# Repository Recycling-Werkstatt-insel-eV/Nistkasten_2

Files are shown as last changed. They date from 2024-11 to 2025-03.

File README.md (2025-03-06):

# Nistkasten Nr. 2
Bei diesem Vogelhaus bestehen sind alle Materialien entweder wiederverwendbar oder wiederaufbereitet und somit auf jeden Fall nachhaltig und umweltfreundlich. Die Vorderseite ist so konstruiert, dass jede Behausung ein Unikat wird. Die einzelnen Platten sind verschiebbar. Das und die Tatsache, dass alle Komponenten verschraubt sind, macht es komplett auseinandernehmbar. Teile können somit leicht ersetzt, ausgetauscht und gereinigt werden. Je nach Vogelart, ob Höhlen- oder Halbhöhlenbrüter kann die Öffnung der Vogelart angepasst werden. Die Kombination aus recyceltem Kunstoff und Holz erzeugt einen echten Hinkucker. 

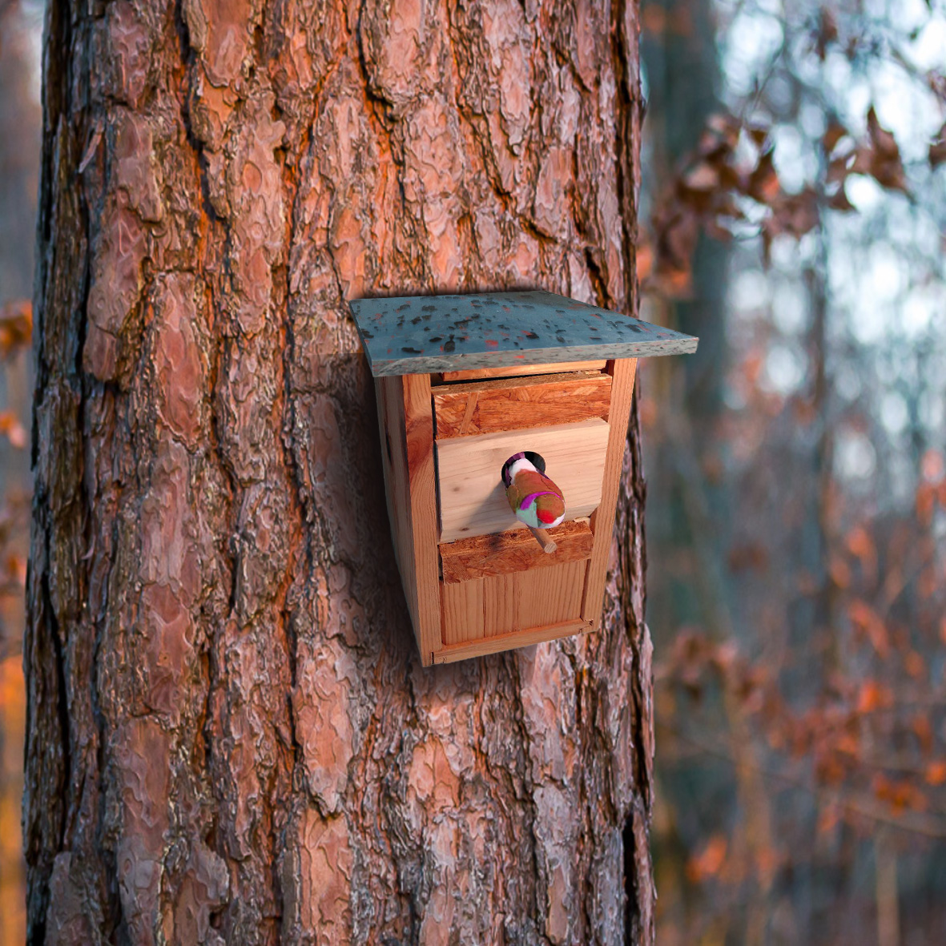
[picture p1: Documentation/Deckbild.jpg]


__Du möchtest dieses Vogelhaus bauen?__ 

Um dieses Vogelhaus nach unserer Methode zu bauen, sieh dir bitte folgende Dokumente an: 

Zum einen empfehlen wir einen Blick in die [Checkliste](./Documentation/Checkliste.md) zu werfen um dir einen Überblick zu machen was es allgemein zu beachten gilt. Anschließend lohnt es sich unseren Vorschlag für die [Fertigung der Einzelteile](./Documentation/Anleitung_Fertigung.md) gewissenhaft zu befolgen, damit die [Anleitung für den Zusammenbau](./Documentation/Anleitung_Aufbau.md) der Einzelteile reibungslos funktioniert. Ergänzend kannst du dir die [Technischen Zeichnungen](./Documentation/Vogelhaus_Ivonne_Technische_Zeichnungen.pdf) dieses Vogelhauses anschauen. Gerade für den Fall, dass du den Entwurf weiterentwickeln möchtest, steht dir jeweils eine [CAD-Datei im STEP Format](./CAD/CAD_Ivonne_Vogelhaus.STEP) und eine
[CAD Datei im STL Format](./3D_printing/CAD_Ivonne_Vogelhaus.STL) zur Verfügung. 

# Allgemeines zum Projekt

Bei diesem Vogelhaus handelt es sich um einen von __4 Entwürfen__ aus einer Reihe innerhalb eines Projekts, in dem wir uns zur Aufgabe gemacht haben, kreative innovative und nachhaltige Ideen für Tierbehausungen zu finden und alte Lösungen zu überdenken. Unseren Fokus haben wir auf Vogelbehausungen gelegt. Und wer sind "wir"? Wir sind Menschen aus der Offenen [Recycling-Werkstatt von Insel e.V.](https://werkstatt.insel-ev.de/) in Hamburg. Besucht uns gerne auf unserer Website oder noch besser persönlich, wir freuen uns auf euch! 

Hier kommt ihr zur [Übersicht](https://github.com/Recycling-Werkstatt-insel-eV/Nistkasten_main_Uebersicht) der folgenden Entwürfe
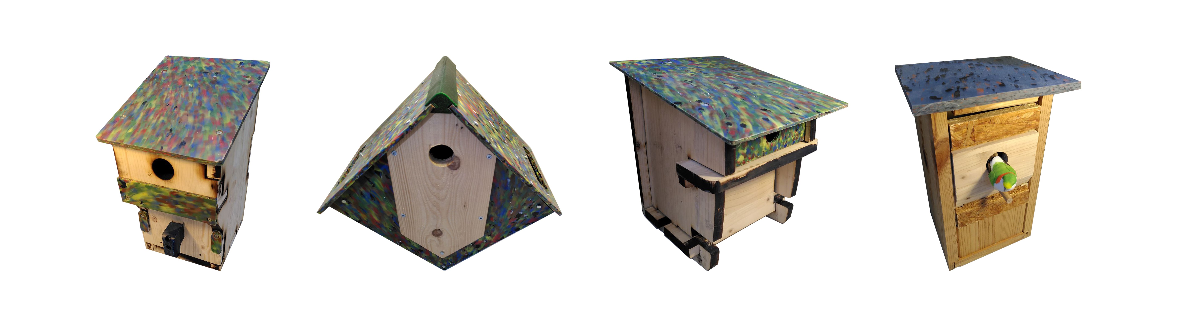
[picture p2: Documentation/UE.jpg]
 
Gefördert von der [Deutschen Stiftung Engagement und Ehrenamt](https://www.deutsche-stiftung-engagement-und-ehrenamt.de/foerderung/) haben wir im Laufe des Jahres 2024 zusammen mit Schüler_innen-Gruppen, Expert_innen vom [NABU](https://www.nabu.de/) und anderen klugen Köpfen getüftelt, wie wir Zeiten, in denen die Umwelt und Natur so schutzbedürftig wie noch nie sind, einen sinnvollen Beitrag leisten können. In Ideen- und Bau- Workshops sind dabei schlussendlich die 4 Konzepte entstanden und umgesetzt worden, die wir euch hier vorstellen wollen. 

__Und was macht unsere Entwürfe besonders?__
Besonders wichtig war uns unter anderem, dass die verwendeten Materialien möglichst nachhaltig sind und eingesetzt werden. Das heißt sie sollen wenig oder gar nicht neu produziert werden müssen. Wir wollen mit Dingen arbeiten, die es schon gibt und diese wieder aufbereiten und neu verwenden. Dafür haben wir in jedem Entwurf recycelten Kunststoff aus unserer Werkstatt verwendet. Dieser besteht aus geschredderten, geschmolzenen zu Platten gepressten Alltagsgegenständen, die sonst in den Müll gewandert wären. Außerdem sind alle Bestandtteile wieder voneinander trennbar. Es wurden keine Klebstoffe und nur wenige Schrauben verwendet. Modulare Systeme ermöglichen zusätzlich das Austauschen und ersetzen einzelner Bestandtteile, sodass die Vogelhäuser leicht repariert werden können und teilweise mehrere Funktionen und Varianten in einem Entwurf beinhalten.  

Aber wie das halt so ist... Kein Entwurf ist perfekt durchdacht. Und genau da kommt ihr ins Spiel. Wir wollen unser Projekt der Community zur Verfügung stellen und euch herzlich einladen die Vogelhäuser __nachzubauen, oder sogar weiterzuentwickeln__. Die Informationen, die  ihr genau dafür benötigt und wie ihr Schritt für Schritt vorgeht, findet ihr in den beiligenden Vogelhaus-Projekten. Von eher unkomplizierten Ideen, die mit einfachen Handwerkzeugen gefertigt werden können, bis hin zu gelaserten oder CNC- gefrästen z.T. herausfordernden Systemen ist für jede_n etwas dabei. Alles kann nichts muss und das gilt auch für die euch zur Verfügung stehenden Mittel. Von uns kommen einige gut gemeinte Ratschläge für die Umsetzung, fühlt euch jedoch gerne frei manches im Sinn eurer Möglichkeiten anders zu machen. Schaut euch gerne um ob und welches Vogelhaus etwas für euch ist, viel Spaß beim bauen und weiterdenken!

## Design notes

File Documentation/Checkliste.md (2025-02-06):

# Checkliste

Unabhängig davon ob ihr eines der Vogelhäuser nachbaut, weiterentwickelt oder einen ganz neuen Entwurf kreiren und aufhängen wollt, gibt es einige wichtige Dinge zu beachten, die für die Umwelt, die Tiere und den Erfolg des Projekts mehr oder weniger wichtig sein können. 
Hier findet ihr eine Übersicht an Checkpunkten an denen wir uns oriententiert haben. 

__Schutz vor Nesträubern__

Viele Tierarten, insbesondere Vögel sind heutzutage stark bedroht. Neben anderen Faktoren sind Nesträuber wie Waschbären, Marder und Hauskatzen dafür verantwortwortlich. Um zu verhindern, dass diese Tiere die Brut der Singvögel bedrohen gibt es bewährte Maßnahmen:

1. Gestalte die Einflugöffnung gerade so groß, dass nur der Nistvogel und vergleichbargroße Arten durchpassen.
2. Baue einen vorgezogenen Zwischenboden in das Vogelhaus, (so wie wir es z.B. bei den Vogelhäusern "Stecksystem" und "Oskar" gemacht haben).
   In dieser Form haben die Räuber Schwierigkeiten bis zur Brut hinunter zu greifen. 
4. Bringe den Vogelkasten idealerweise in einer Höhe von mindestens 2 Metern an, sodass es manchen Räubern schwerer fällt die Brut zu wittern und 
diese zu erreichen.

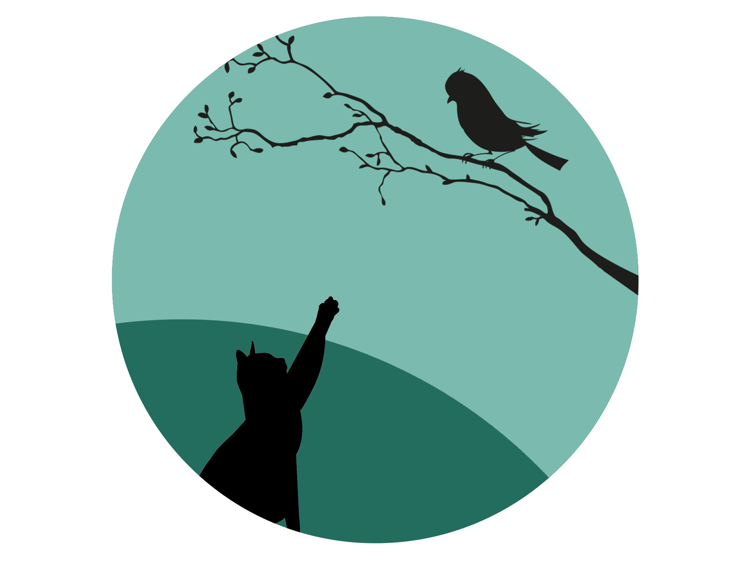
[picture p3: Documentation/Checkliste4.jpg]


__Der passende Ort__

Achte zudem darauf, dass du für dein Vogelhaus einen geeigneten Ort findest, wo sich die Tiere natürlicherweise wohl fühlen. 
Es sollte dort möglichst viel unterschiedliche Vegetation geben, die für viele Lebewesen einen Rückzugsort zum Verstecken und eine wichtige Nahrungsgrundlage bietet. Nur in einem gesunden Ökosystem siedeln sich auch Vögel an um dort zu brüten. Ich denke es sollte klar sein welches der beiden folgenden Beispiele auf dem Bild geeigneter ist.  

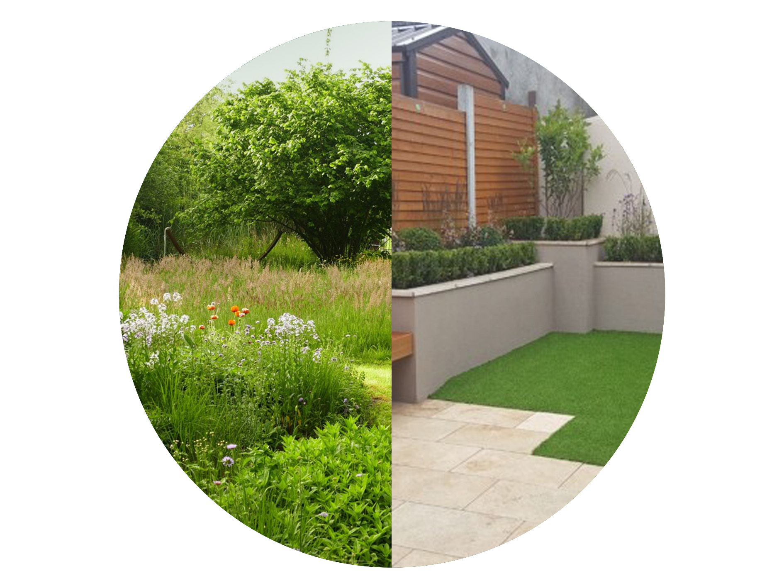
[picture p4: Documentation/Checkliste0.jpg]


__Die richtigen Maße__

Unter dem folgenden Link https://www.nabu-rlp-sued.de/artenschutz/bauanleitungen-f%C3%BCr-nisthilfen/ 
des Nabu Rheinland Pfalz findet ihr viele Infos zu dem Thema, auch die Maße für Vogelhäuser, welche sich etabliert haben um möglichst viele Vogelarten zu erreichen, indem sie gerade groß genug sind und entsprechend Material sparen. Es reicht aber wenn sie euch als ungefährer Anhaltspunkt dienen. 

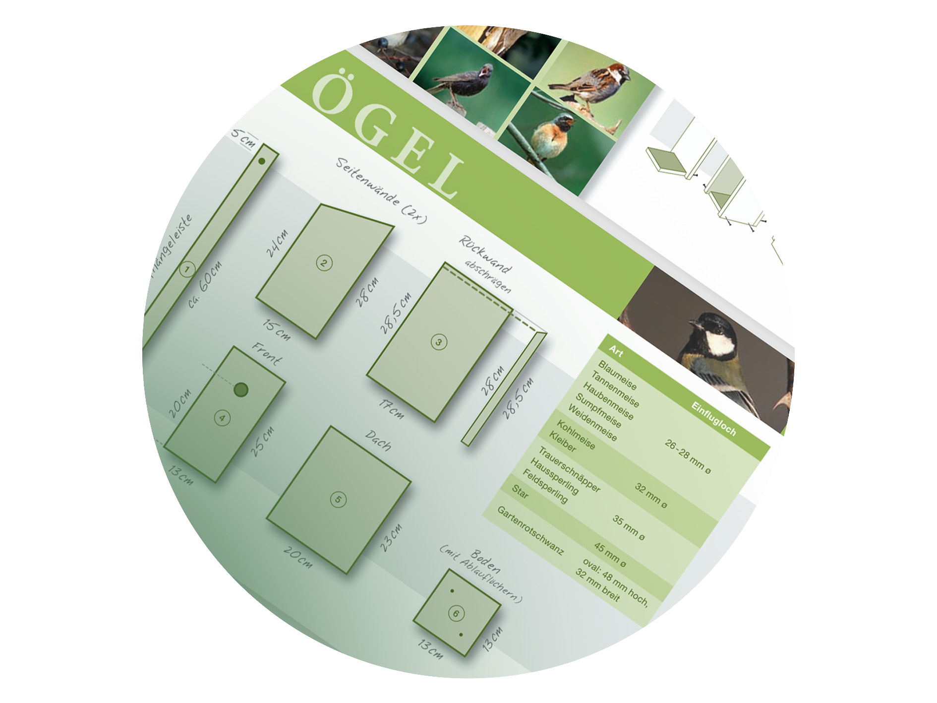
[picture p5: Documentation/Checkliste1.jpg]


__Reinigung des Nistkastens__

Leider müssen Nistkästen ein mal im Jahr nach der Brutsaison gereinigt werden, damit sie sich nicht mit Nistmaterial anfüllen und irgendwann nicht mehr bezogen werden. Gestalte den Kasten also idealerweise so, dass er sich unkompliziert öffnen und reinigen lässt. Die Brutsaison der meisten Singvögel ist im Frühsommer von Mai bis Juli. Ab August lohnt sich der erste Blick ins Innere ob der Mieter mitlerweile ausgezogen ist. 

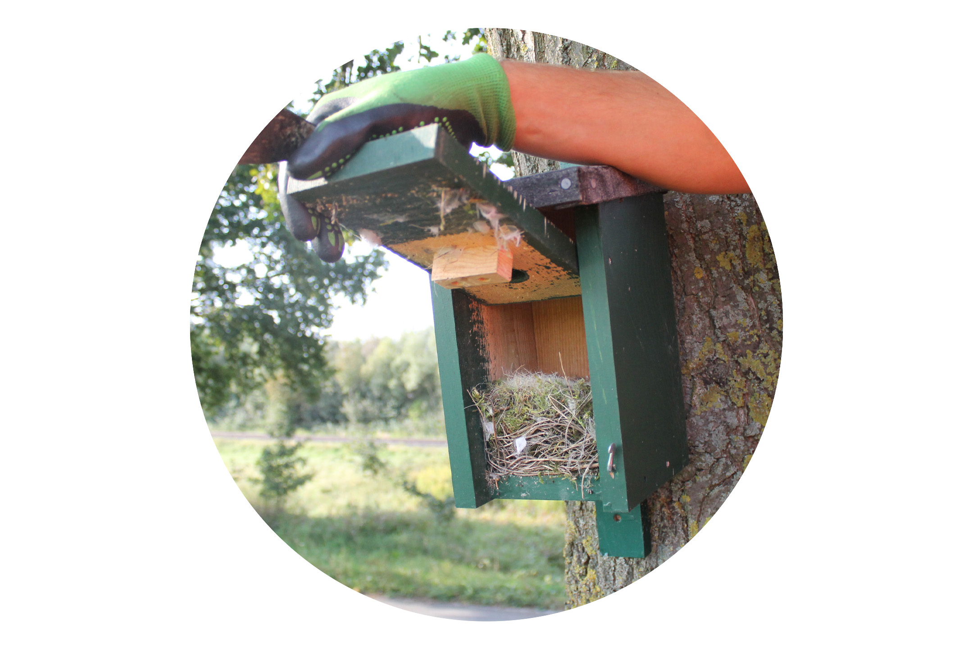
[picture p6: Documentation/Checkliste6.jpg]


__Die ideale Befestigung__

Einfache Eisen- oder Kupfernägel können für einige Baumarten problematisch sein, da sie für diese in einigen Fällen gesundheitsschädlich sind und der Pflanze schaden. Zudem gehen Werkzeuge wie Kettensägen beim Fällen der Bäume kaputt wenn sie in hartes Metall sägen. Um dies zu verhindern ist es ratsam Aluminium-Nägel zu verweden.   

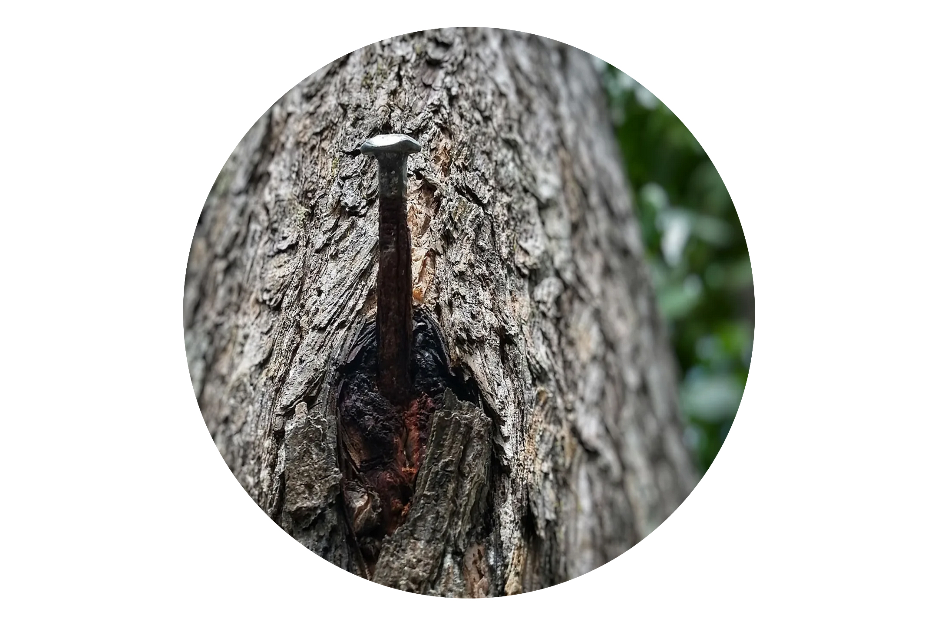
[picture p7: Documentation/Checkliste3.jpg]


__Geeignetes Material__

Die Materialwahl der Tierbehausung ist gleich aus mehreren Gründen besonders wichtig. Beachte dabei bitte folgende Punkte: 

1. Das Material sollte möglichst atmungsaktiv sein, denn wenn das Innere des Hauses mal nass wird und nicht richtig trocknet, kann sich Schimmel bilden, es setzen Fäulnisprozesse ein und Parasiten haben bei den Nestlingen leichteres Spiel. Das schadet der Gesundheit der Brut und verkürzt zudem die Langlebigkeit der Behausung.
2. Achte darauf, dass die verwendeten Materialien nicht vorbehandelt oder beschichtet wurden. In vielen Fällen verstecken sich giftige und umweltschädliche Chemikalien in und auf wiederverwerteten Gegenständen.
3. Denke an die Nachhaltigkeit deiner Materialien. Nachhaltig ist ein Material z.B. dann, wenn es sich mit der Zeit durch die äußeren Einflüsse natürlich zersetzt und komplett wieder in den biologischen Stoffkreislauf zurückgeführt werden kann. Versuche zudem möglichst keine neuen Materialien zu verwenden, sondern bereits existierende Werkstoffe neu aufzubereiten und wiederzuverwenden. Das klappt nicht immer, aber in vielen Fällen. Auch recycelter Kunststoff ist in eingen Fällen deutlich nachhaltiger als manche anderen Alternativen. Bspw. unsere Dächer bestehen aus wasserabweisendem Kunststoff um die Lebensdauer der Behausungen zu verlängern. 

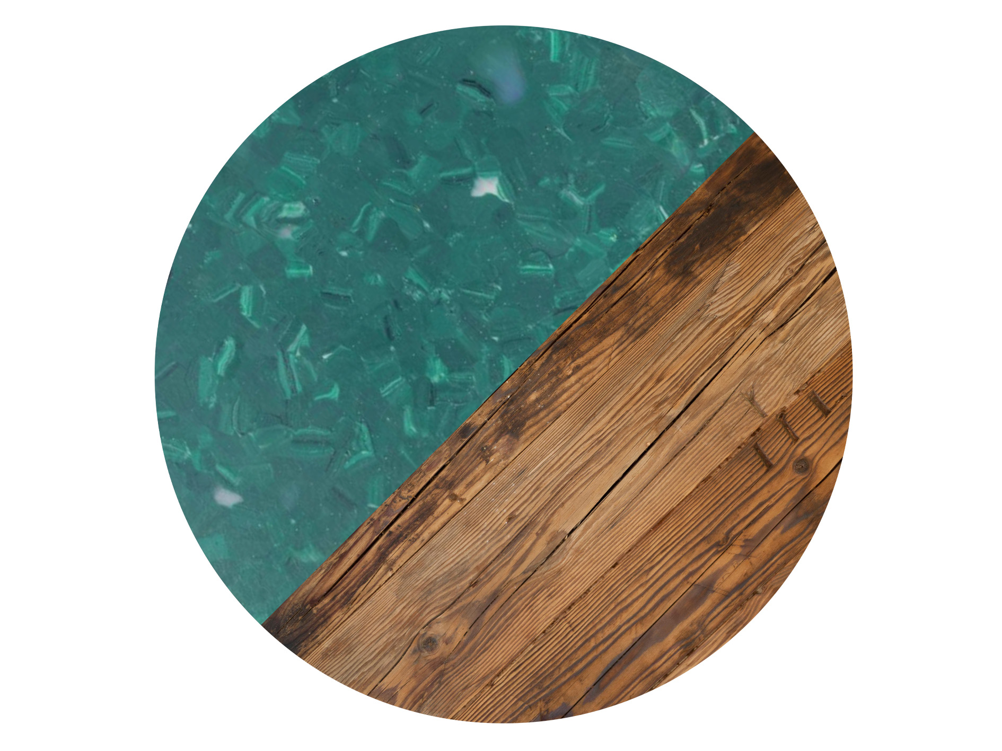
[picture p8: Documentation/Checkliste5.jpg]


Wenn du möglichst viele dieser Punkte beachtest, hast du in deinem Vorhaben schon halb gewonnen.

__Viel Spaß bei der Umsetzung!__

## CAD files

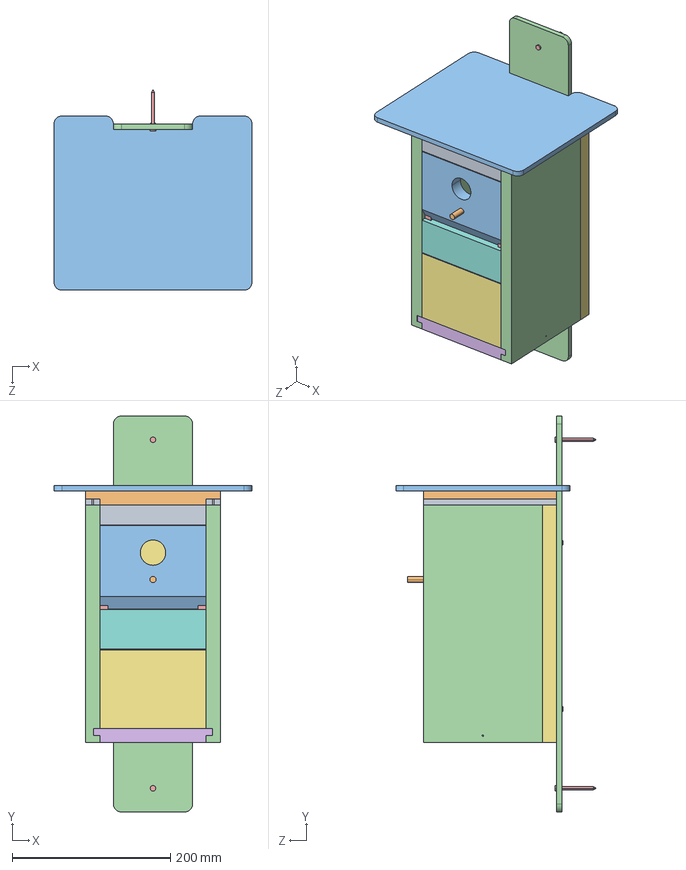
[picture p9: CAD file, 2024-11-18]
CAD/CAD_Ivonne_Vogelhaus.STEP
250.0 x 500.0 x 253.0 mm

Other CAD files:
3D_printing/CAD_Ivonne_Vogelhaus.STL

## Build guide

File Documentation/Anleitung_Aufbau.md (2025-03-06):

# Aufbauanleitung

Hier findet ihr die Bauanleitung von Vogelhaus Nr. 2. Achtet darauf, dass ihr alle entsprechenden Einzelteile im Voraus gefertigt habt, bevor ihr versucht, die Teile zusammenzusetzen. Die Reihenfolge nach dem folgenden Prinzip ist sehr wichtig, damit der Zusammenbau einfach und fehlerfrei abläuft. Bei diesem Beispiel werden 2 Baugruppen hergestellt, die am Ende zusammengesetzt werden. 

__Benötigte Werkzeuge und Hilfsstoffe für den Zusammenbau__

1. Schraubendreher oder Akkuschrauber
3. Schraubzwingen oder mindestens eine helfende Person
4. Schrauben: Für den Bau der Behausung M3 zwischen 12 und 40 mm (12 Stk.)
   und für die Montage Nägel oder Schrauben M3-M5 mit einer Mindestlänge von 80 mm (2 Stk.)
5. Schleifpapier (Körnung 80-200) oder Holzpfeilen für Korrekturen oder abschließende Schönheitsarbeiten.

__Baugruppe 1__ In Baugruppe 1 fertigst du den Hauptkörper des Vogelhauses. 
__Schritt 1__ Zu Beginn werden die hölzernen Seitenwände mit der Bodenplatte verbunden. Hierzu benötigst du 3 Schraueben der Größe M3/M4 mit einer Mindestlänge von 25 mm, also mindestens 7 mm länger als die Platte dick ist (18mm).
__Tipp:__ Benutze einen Schraubstock, Schraubzwingen oder lasse dir beim Zsammenbau helfen, damit die Kanten der Bauteile bündig und rechtwinklig zueinander stehen, wenn du die Schrauben eindrehst. 
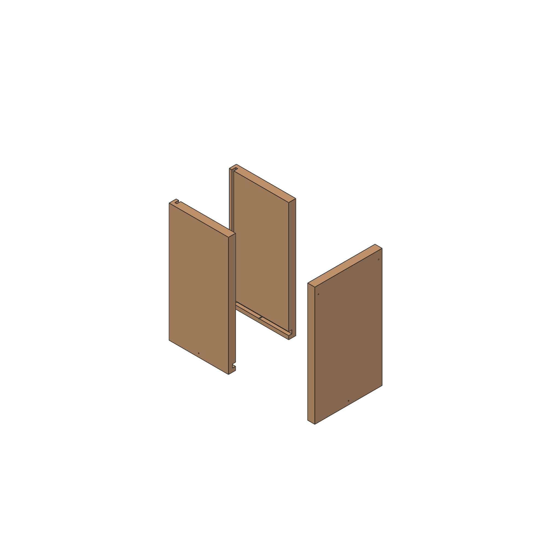
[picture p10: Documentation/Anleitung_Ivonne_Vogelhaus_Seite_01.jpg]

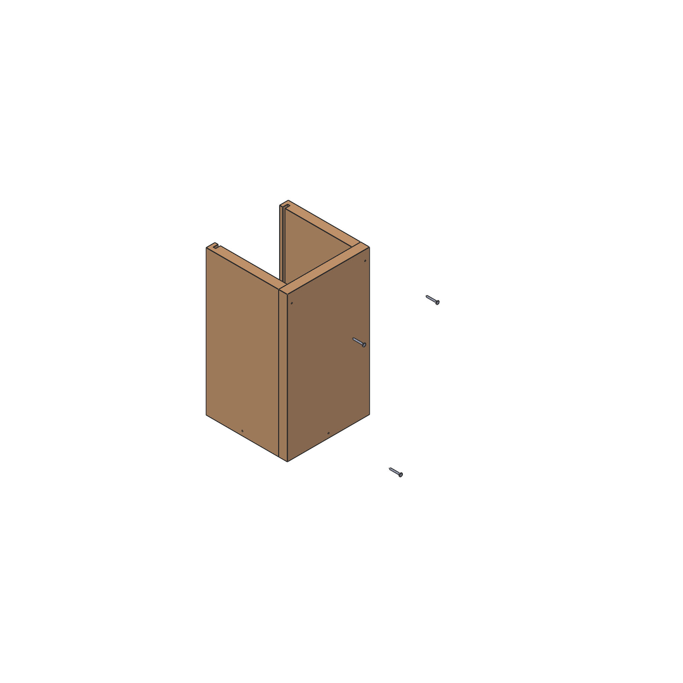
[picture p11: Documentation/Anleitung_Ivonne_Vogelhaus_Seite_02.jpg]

__Schritt 2__ Die Bodenplatte lässt sich nun von vorne in die Baugruppe einschieben. Benutze hierfür gegebenenfalls zusätzlich Schrauben, (M3/M4, Mindestlänge 25 mm) um die Bodenplatte zu fixieren, wie im folgenden dargestellt:
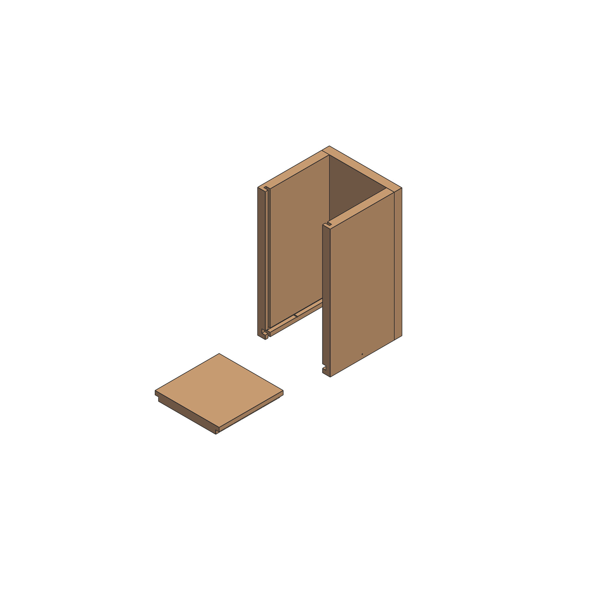
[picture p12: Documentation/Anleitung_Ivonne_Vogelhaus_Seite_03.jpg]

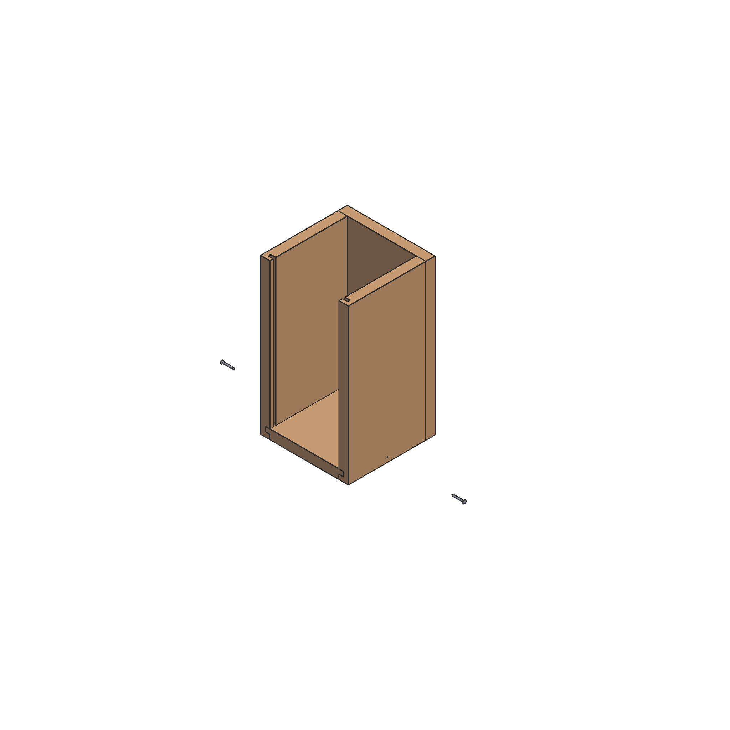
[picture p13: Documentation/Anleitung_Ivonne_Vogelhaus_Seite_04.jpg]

__Schritt 3__ Anschließend werden die länglichen Kunststoffstreifen (282/20/5 mm) von oben in die Nuten der Seitenwände geschoben. Achte darauf, dass diese richtig einrasten und nicht überstehen. 
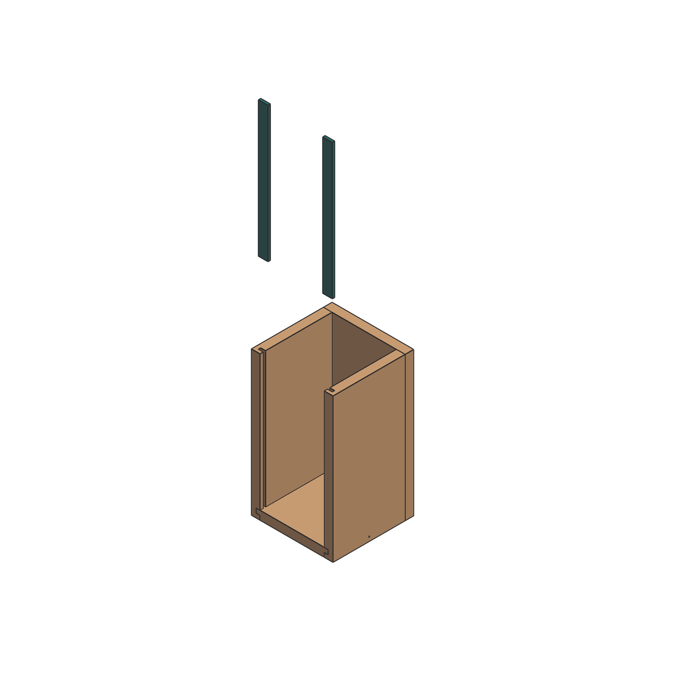
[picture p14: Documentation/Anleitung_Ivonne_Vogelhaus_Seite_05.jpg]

__Schritt 4__ Jetzt kannst du 2 der dünnen Kunstoffstreifen (168/8/8 mm) mit jeweils 2 Schrauben der Größe M3, Länge zwischen 12 und 25 mm befestigen. 
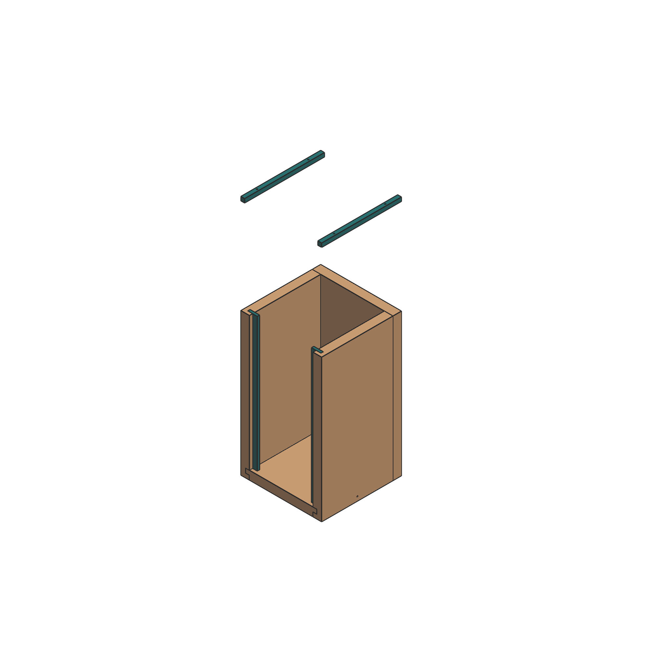
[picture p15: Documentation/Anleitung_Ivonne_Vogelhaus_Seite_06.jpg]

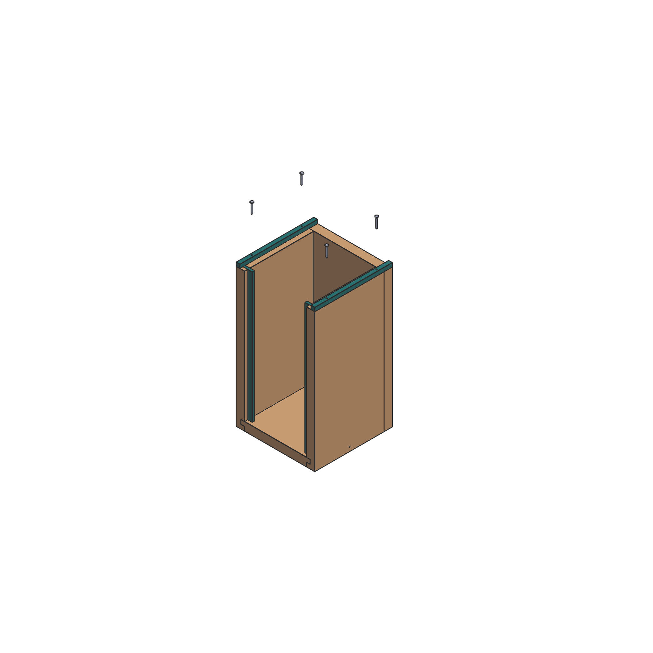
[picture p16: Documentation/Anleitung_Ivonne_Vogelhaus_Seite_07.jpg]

__Schritt 5__ Nun schiebe die Teilstücke der Frontwand in die entstandene Halterung. Achte auch hier darauf, dass kein Teil übersteht, aber auch keine größeren Lücken entstehen.
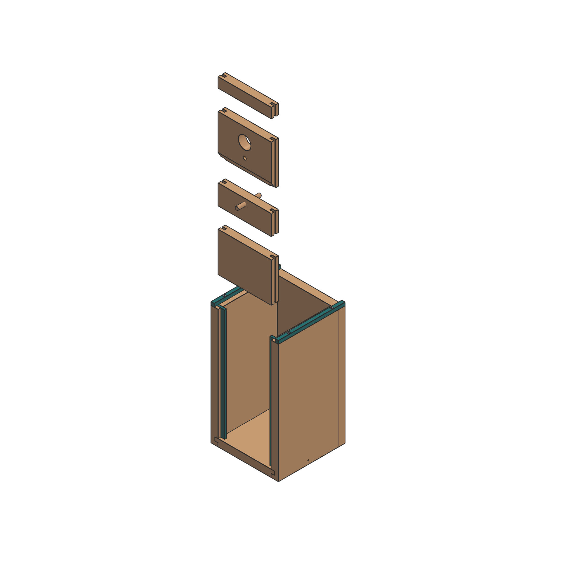
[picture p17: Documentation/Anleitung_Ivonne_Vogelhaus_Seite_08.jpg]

__Baugruppe 2__ In Baugruppe 2 fertigst du das Dach des Hauses. 
__Schritt 6__ Lege die innere Dachplatte aus Holz auf die äußere Dachplatte aus Kunststoff. Auf die eingefrästen Ränder der Holzplatte lege anschließend die verbleibenden 2 Kunststoffstreifen (168/8/8). Hierfür nutze ebenfalls jeweils 2 Schrauben der Größe M3, Länge zwischen 12 und 25 mm
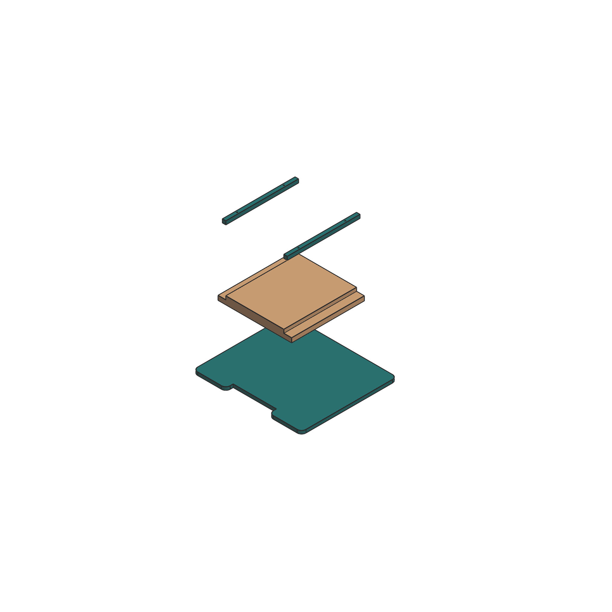
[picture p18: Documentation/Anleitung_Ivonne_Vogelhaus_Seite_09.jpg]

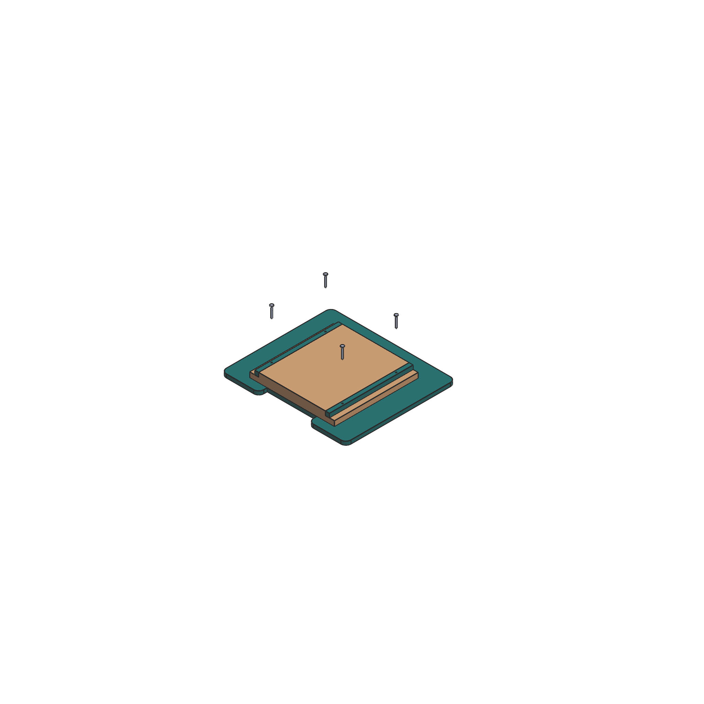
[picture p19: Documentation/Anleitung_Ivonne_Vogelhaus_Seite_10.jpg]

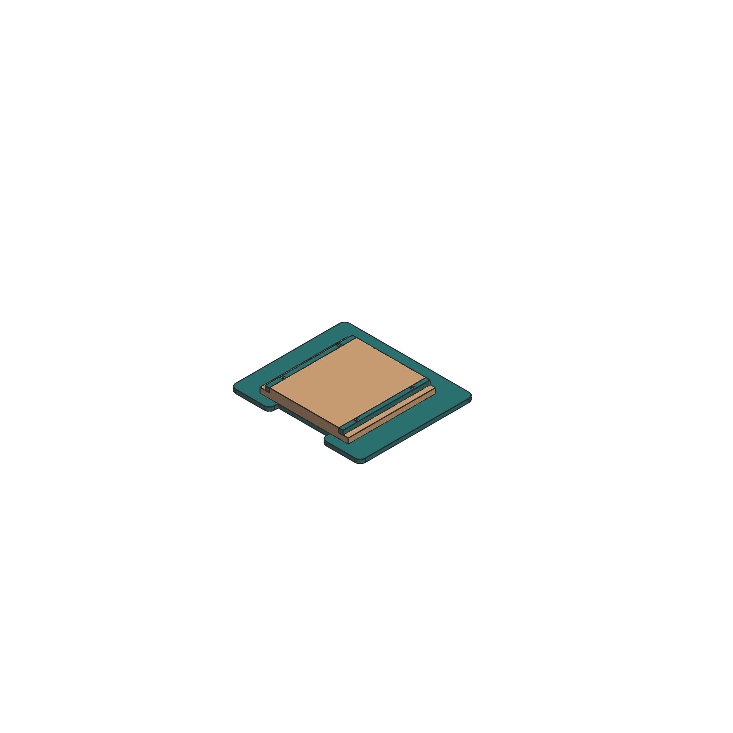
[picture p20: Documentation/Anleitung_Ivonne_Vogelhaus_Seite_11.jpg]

__Zusamnenfügen der Baugruppen 1 und 2__ 

__Schritt 7__ Du kannst nun folgendermaßen das Dach auf den Hauptkörper setzen. Achte darauf, dass die eingefräste Kante des Daches und die Rückwand eine vertikale Linie bilden, damit sich das Kunststoffbrett zur Montage abstandslos befestigen lässt. 
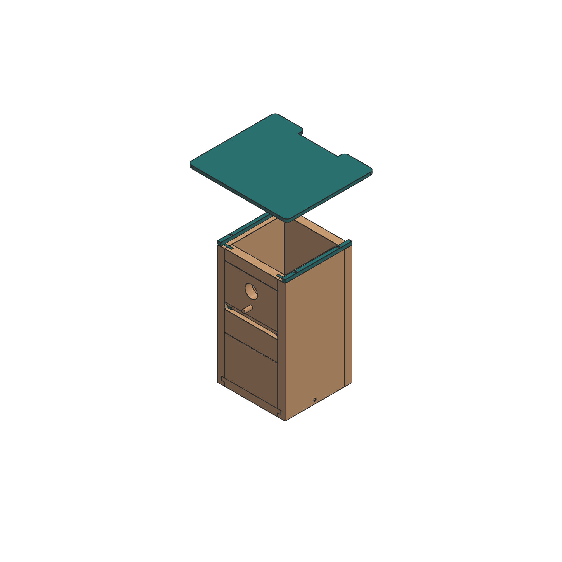
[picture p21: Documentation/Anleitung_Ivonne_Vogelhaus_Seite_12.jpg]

__Schritt 8__ Schraube nun mit 2 M3 Schrauben des Länge 25-28 mm das hintere Brett aus Kunststoff fest. Achte daruaf, dass die Nägel nicht kürzer oder länger als angegeben sind, damit die Konstruktion fest genug hält, die Nägel aber nicht ins Innere der Behausung durchragen. 
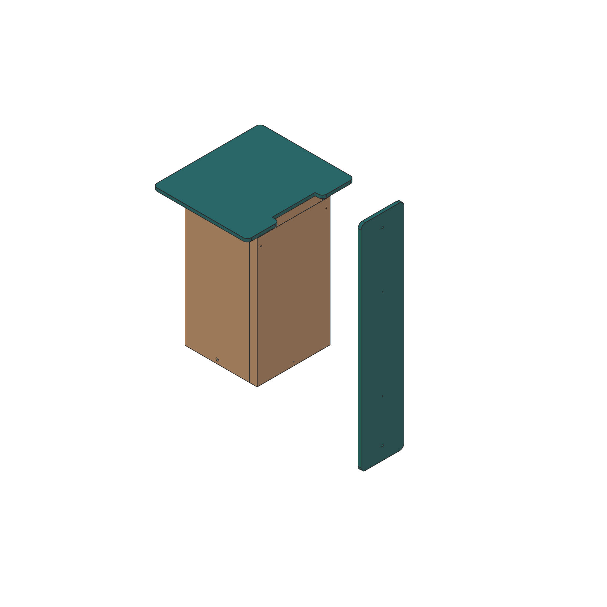
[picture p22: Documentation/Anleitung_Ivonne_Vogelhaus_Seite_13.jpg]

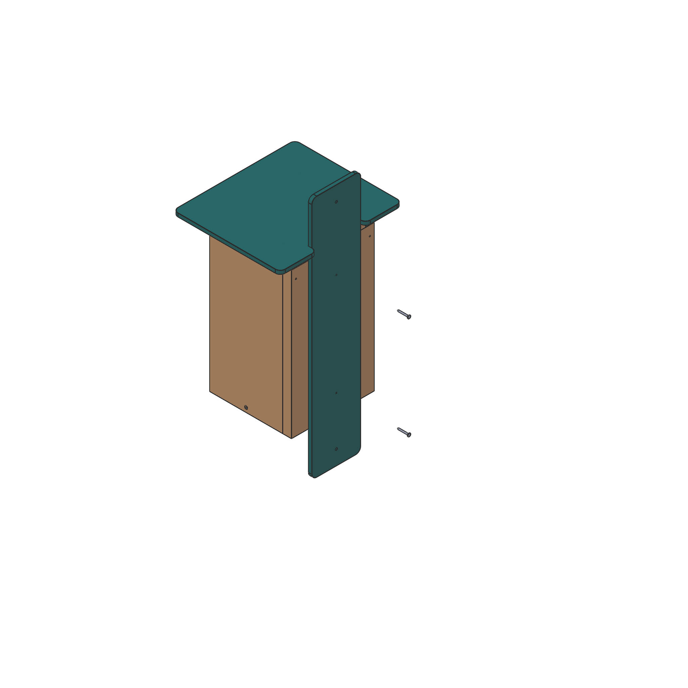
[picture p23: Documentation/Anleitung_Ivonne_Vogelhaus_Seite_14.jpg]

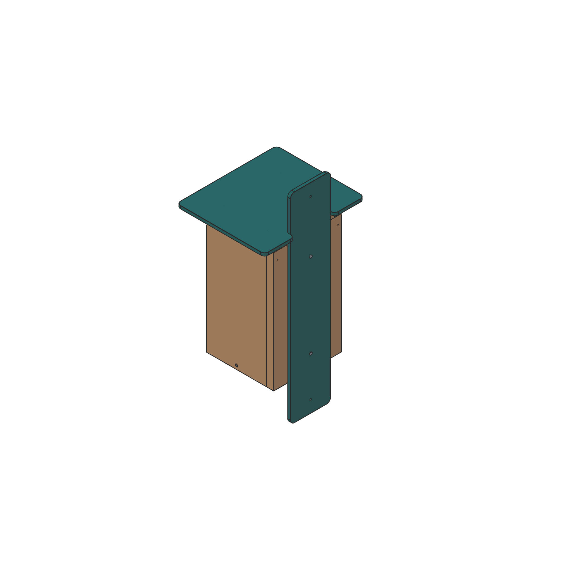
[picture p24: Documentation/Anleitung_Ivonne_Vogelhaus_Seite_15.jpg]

Dein Vogelhaus ist nun __fertig__ aufgebaut.

__Montage__ Jetzt geht es nur noch um die richtige Befestigung beim Aufhängen an einem geeigneten Baum oder bspw. einer Hauswand. Benutze - solltest du dich für einen Baum entscheiden-  wenn möglich Aluminiumnägel mit einer Länge von mindestens 80 mm. Nägel aus Eisen sind aber auch in Ordnung. 
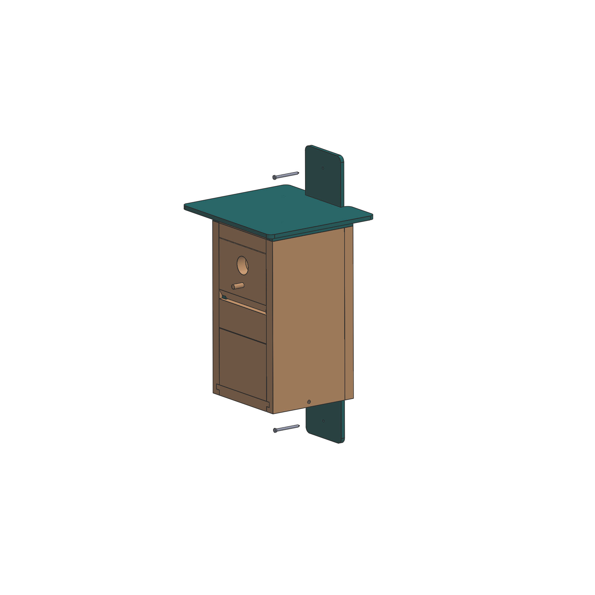
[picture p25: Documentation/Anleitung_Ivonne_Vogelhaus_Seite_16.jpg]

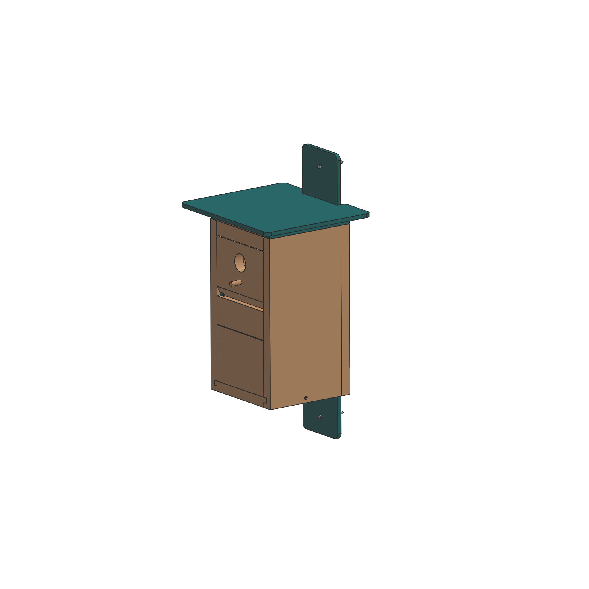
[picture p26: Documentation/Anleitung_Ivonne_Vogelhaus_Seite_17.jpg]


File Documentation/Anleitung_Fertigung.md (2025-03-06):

# Anleitung zur Fertigung der einzelnen Bauteile

Hier und im folgenden ist beschrieben wie beim Bau von Vogelhaus Nr. 2 idealerweise vorgegangen werden kann. 
Es handelt sich um begründete Vorschläge und Tipps, es gibt auch andere Möglichkeiten.

a. __Fräsen der Teile mit CNC__ Hierfür ist bereits Datei als Vorlage angelegt (siehe Repository im Ordner CAD). Im Ordner Dokumentation findest du die technischen Zeichnungen zu allen Bauteilen, solltest du diese erstellen wollen.
   
b.  __Händische Bearbeitung__ mit herkömmlichen Subtraktionswerkzeugen. Dieser Ansatz ist vermutlich am sinnvollsten. Folgende Werkzeuge benötigst du idealerweise:

   - Eine Sägevorrichtung die sowohl gerade als auch schräge Schnitte vollziehen kann. (Bsp. __Tischkreissäge oder Handkreissäge mit Leitwerk__)
     Die Komponenten sind teilweise relativ klein und unhandlich,
     sieh also bitte davon ab diese mit Handwerkzeugen zu bearbeiten um das Verletzungsrisiko zu minimieren.
     Sollte dies unumgänglich sein, spanne die kleinen Teile in einen __Schraubstock oder mit Schraubzwingen__ fest. 
   - Eine Fräse (z.B. __Oberfräse oder Nutfräse__) zum einen, um die Kanten der Bauteile abzurunden und Konturen nachzuarbeiten, aber hauptsächlich, um die Nuten einzufräsen.
   - __Akkuschrauber oder Standbohrmaschine__ um die vorgesehenen Löcher für die Schrauben vorzubohren.
   - __Bohrer in der größe 2mm und 3 mm__
   - Ggf. eine __Feile u.o. Schleifpapier der Körnung 80- 200__ falls Nachbearbeitungen nötig werden sollten.
   - Ein __Hammer und Nägel__ zur Befestigung der Behausung an einem Baum.  

c. __Vorheriges Lasern__ der Teile. Weniger sinnvoll, aber möglich ist es die Komponenten zu lasern, 
da diese nicht nur vertikale Außenkonturen und Löcher haben, 
sondern auch Fasen und Nuten, die schräg oder nur teilweise durchgehend geschnitten werden müssen. 
Nachdem die Konturen geschnitten wurden müssten einzelne weitere Schritte mit anderen Mitteln erfolgen.

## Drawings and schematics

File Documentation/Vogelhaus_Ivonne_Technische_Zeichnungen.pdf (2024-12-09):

E | E
F | F

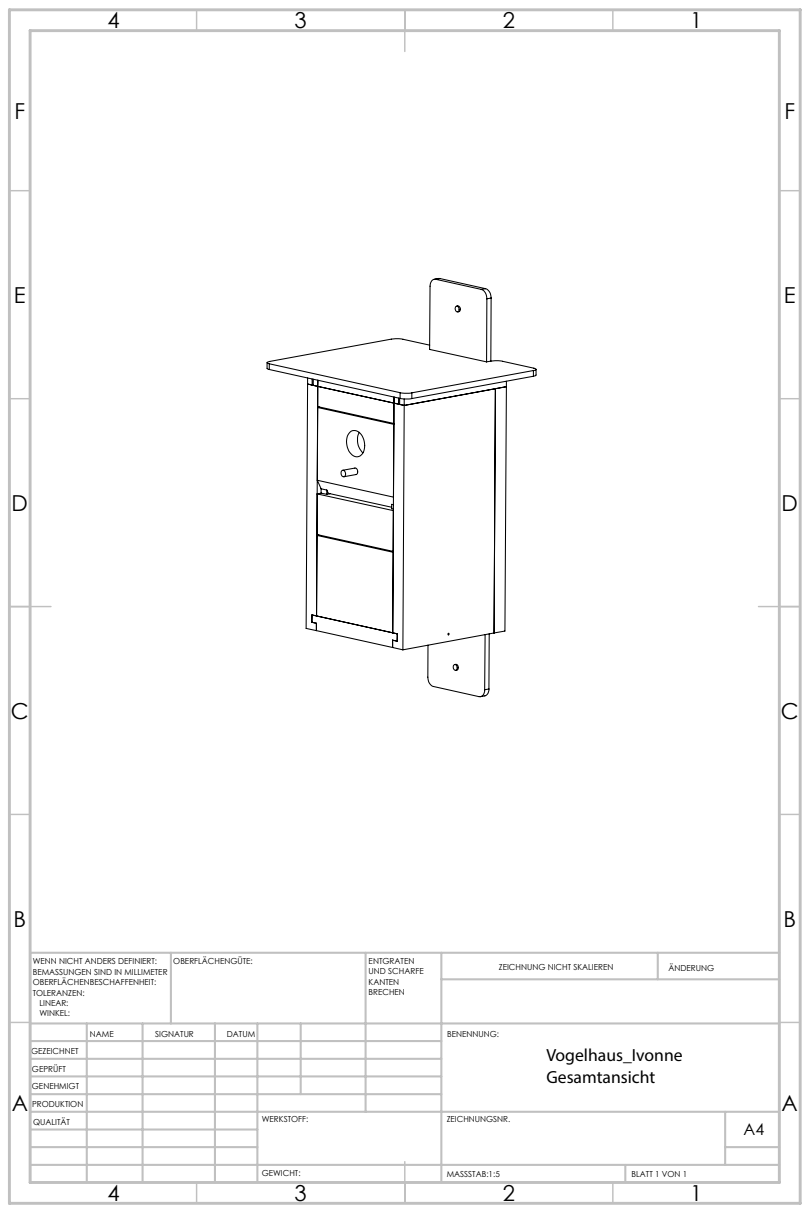
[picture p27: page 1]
GEWICHT:; MASSSTAB:1:5; BLATT 1 VON 1; ZEICHNUNG NICHT SKALIEREN; ÄNDERUNG; ENTGRATEN UND SCHARFE KANTEN BRECHEN; WENN NICHT ANDERS DEFINIERT:; OBERFLÄCHENGÜTE:

BEMASSUNGEN SIND IN MILLIMETER
OBERFLÄCHENBESCHAFFENHEIT:
TOLERANZEN:
LINEAR:
WINKEL:

NAME | SIGNATUR | DATUM | BENENNUNG: Vogelhaus_Ivonne Gesamtansicht
GEZEICHNET
GEPRÜFT
GENEHMIGT
PRODUKTION
QUALITÄT | WERKSTOFF: | ZEICHNUNGSNR. | A4

A

250,00

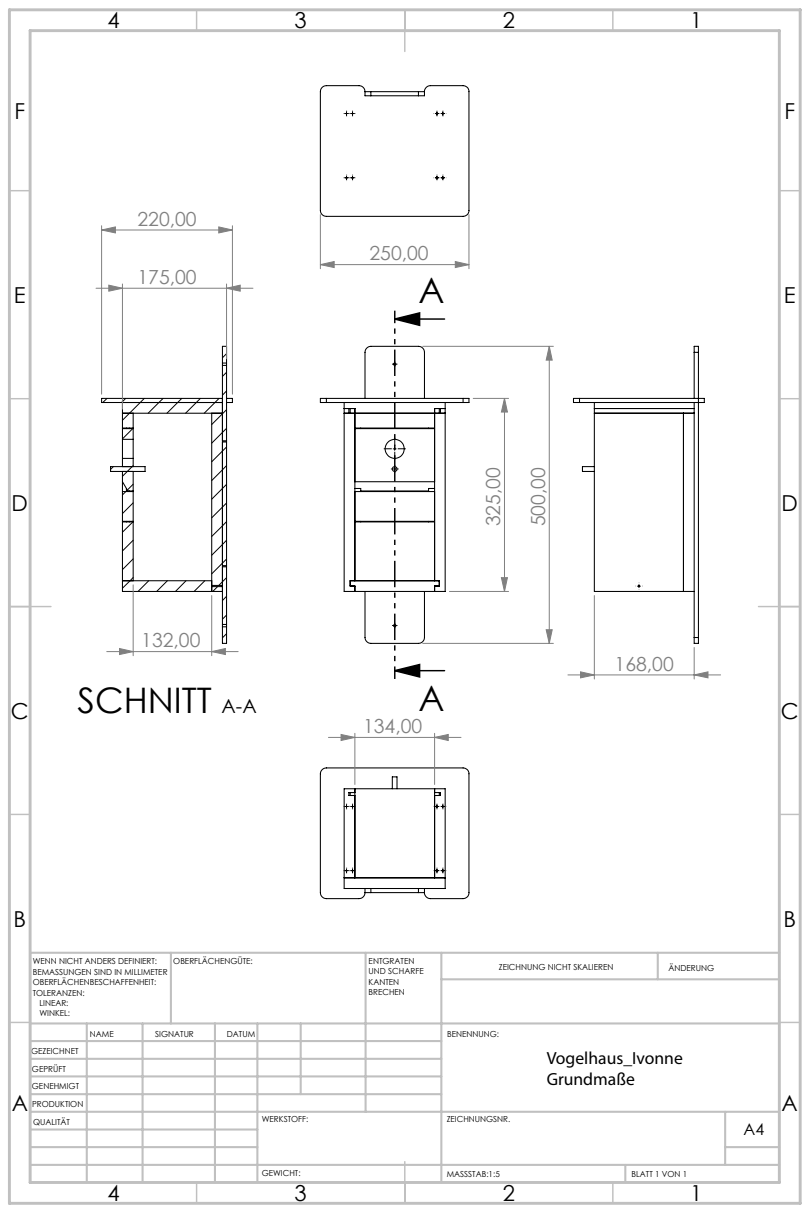
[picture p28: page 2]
132,00 SCHNITT A-A; MASSSTAB:1:5; BLATT 1 VON 1; ZEICHNUNG NICHT SKALIEREN; ÄNDERUNG; ENTGRATEN UND SCHARFE KANTEN BRECHEN; WENN NICHT ANDERS DEFINIERT:; OBERFLÄCHENGÜTE:

BEMASSUNGEN SIND IN MILLIMETER
OBERFLÄCHENBESCHAFFENHEIT:
TOLERANZEN:
LINEAR:
WINKEL:

NAME | SIGNATUR | DATUM | BENENNUNG: Vogelhaus_Ivonne Grundmaße
GEZEICHNET
GEPRÜFT
GENEHMIGT
PRODUKTION

100,00

100,00 | 75,00

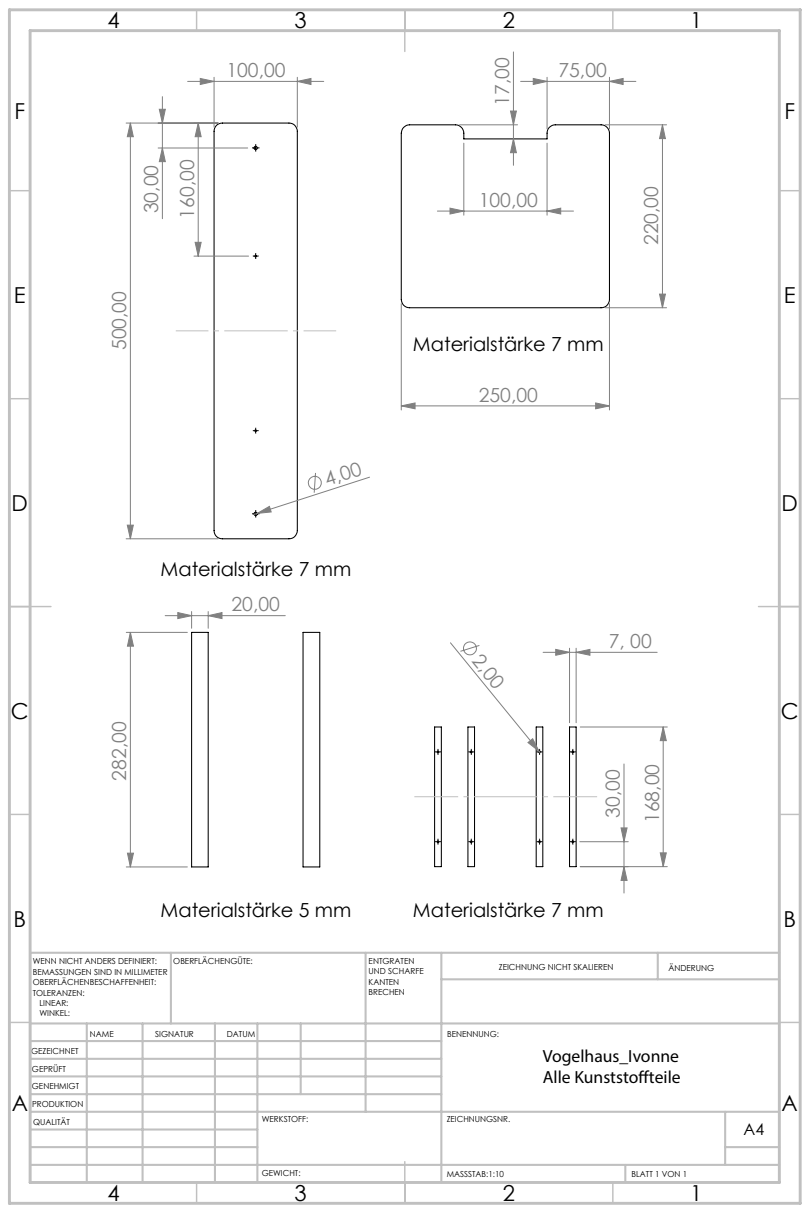
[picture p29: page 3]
Materialstärke 5 mm; Materialstärke 7 mm; MASSSTAB:1:10; BLATT 1 VON 1; ZEICHNUNG NICHT SKALIEREN; ÄNDERUNG; ENTGRATEN UND SCHARFE KANTEN BRECHEN; WENN NICHT ANDERS DEFINIERT:; OBERFLÄCHENGÜTE:

BEMASSUNGEN SIND IN MILLIMETER
OBERFLÄCHENBESCHAFFENHEIT:
TOLERANZEN:
LINEAR:
WINKEL:

NAME | SIGNATUR | DATUM | BENENNUNG: Vogelhaus_Ivonne Alle Kunststoteile
GEZEICHNET
GEPRÜFT
GENEHMIGT
PRODUKTION

170,00

9,00

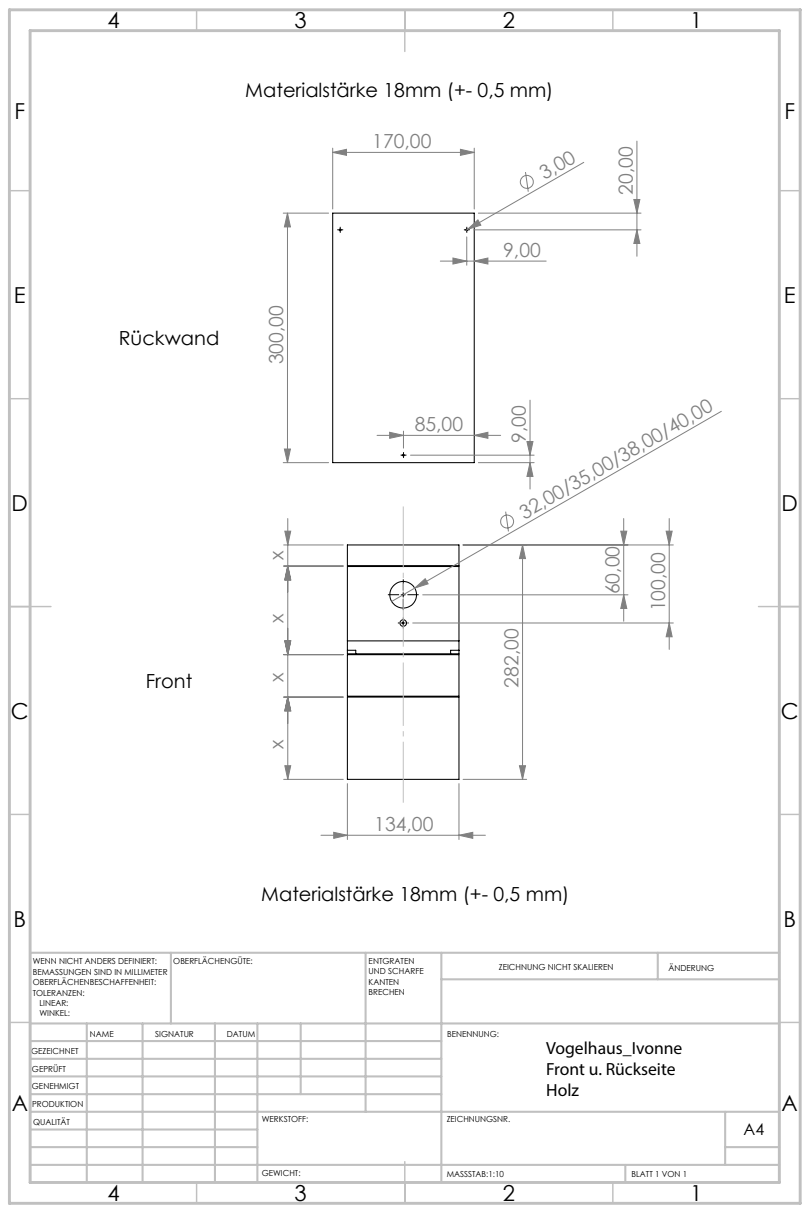
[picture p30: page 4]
Rückwand; Front; Materialstärke 18mm (+- 0,5 mm); ZEICHNUNG NICHT SKALIEREN; ÄNDERUNG; ENTGRATEN UND SCHARFE KANTEN BRECHEN; WENN NICHT ANDERS DEFINIERT:; OBERFLÄCHENGÜTE:

BEMASSUNGEN SIND IN MILLIMETER
OBERFLÄCHENBESCHAFFENHEIT:
TOLERANZEN:
LINEAR:
WINKEL:

NAME | SIGNATUR | DATUM | BENENNUNG: Vogelhaus_Ivonne Front u. Rückseite Holz
GEZEICHNET

GEPRÜFT
GENEHMIGT
PRODUKTION

150,00
18,00 9,00

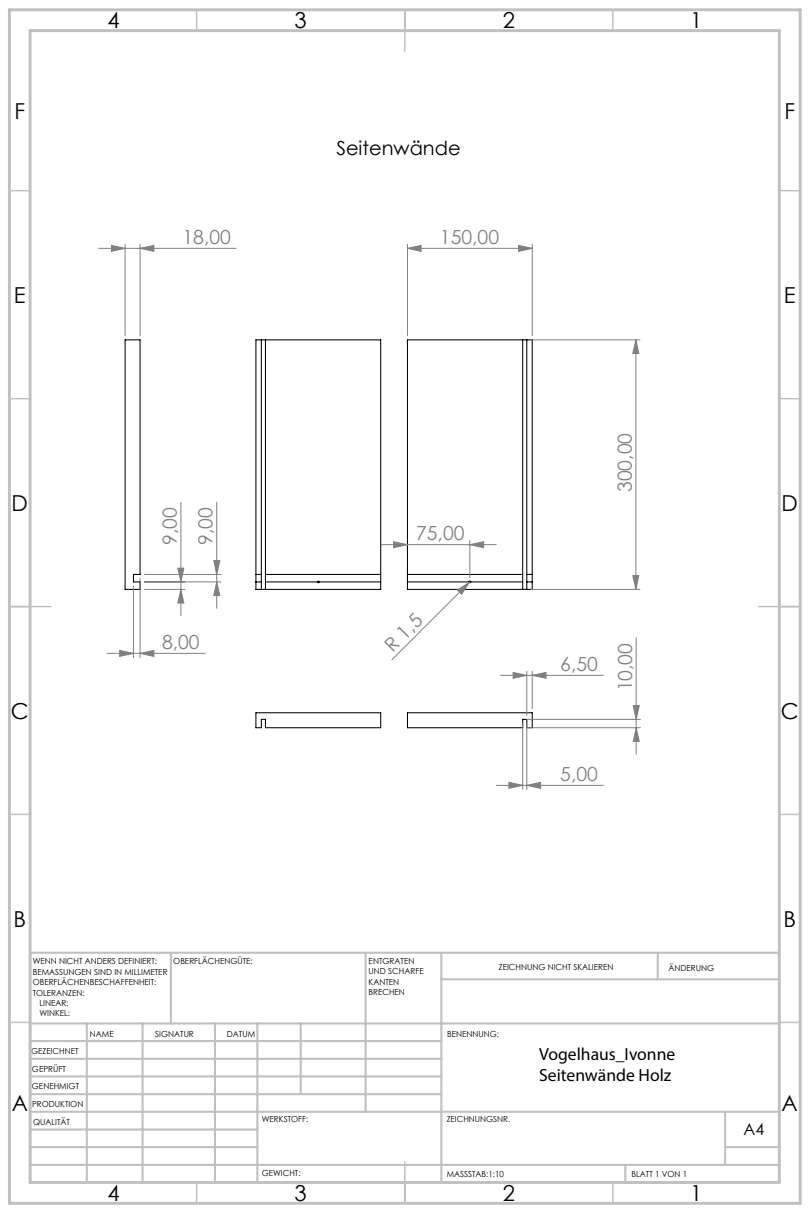
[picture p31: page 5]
Seitenwände; ZEICHNUNG NICHT SKALIEREN; ÄNDERUNG; ENTGRATEN UND SCHARFE KANTEN BRECHEN; WENN NICHT ANDERS DEFINIERT:; OBERFLÄCHENGÜTE:

BEMASSUNGEN SIND IN MILLIMETER
OBERFLÄCHENBESCHAFFENHEIT:
TOLERANZEN:
LINEAR:
WINKEL:

NAME | SIGNATUR | DATUM | BENENNUNG: Vogelhaus_Ivonne Seitenwände Holz
GEZEICHNET
GEPRÜFT
GENEHMIGT
PRODUKTION

170,00

# Dach Holzplatte

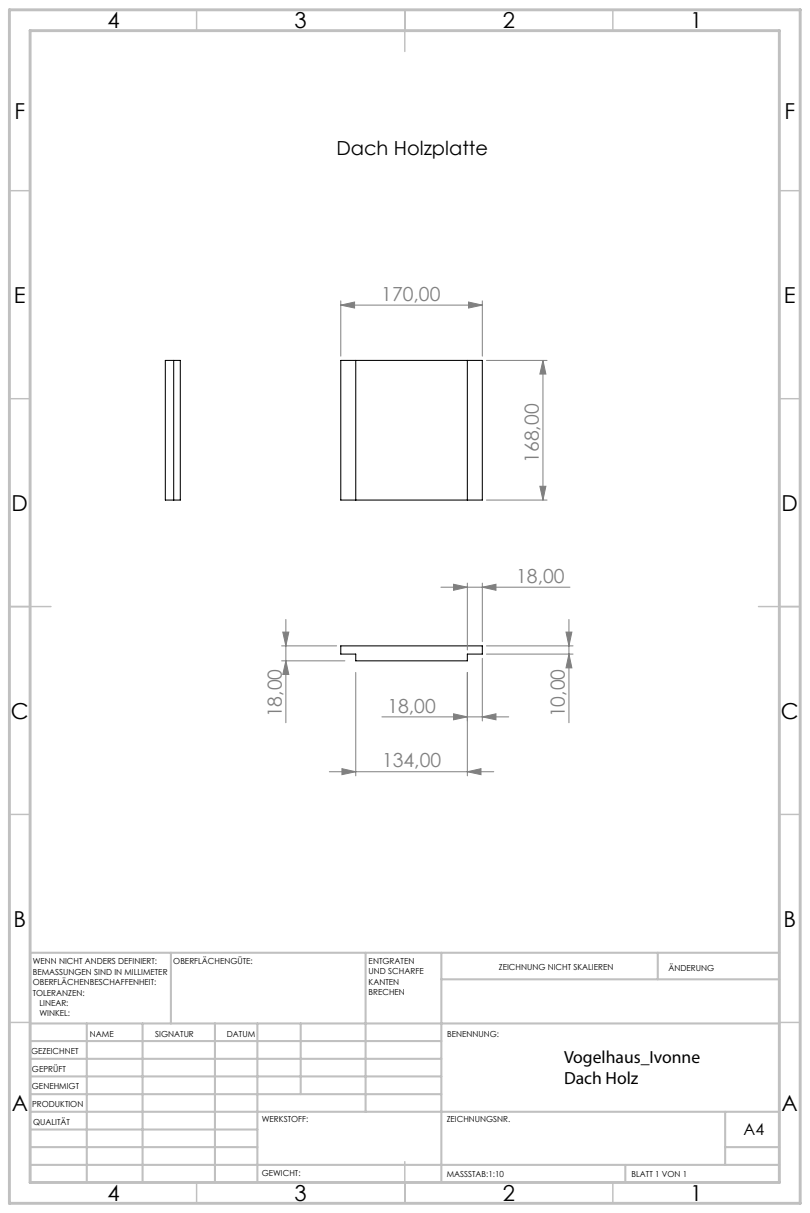
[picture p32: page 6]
ZEICHNUNG NICHT SKALIEREN; ÄNDERUNG; ENTGRATEN UND SCHARFE KANTEN BRECHEN; WENN NICHT ANDERS DEFINIERT:; OBERFLÄCHENGÜTE:

BEMASSUNGEN SIND IN MILLIMETER
OBERFLÄCHENBESCHAFFENHEIT:
TOLERANZEN:
LINEAR:
WINKEL:

NAME | SIGNATUR | DATUM | BENENNUNG: Vogelhaus_Ivonne Dach Holz
GEZEICHNET
GEPRÜFT
GENEHMIGT
PRODUKTION

# Boden Holzplatte

E | E

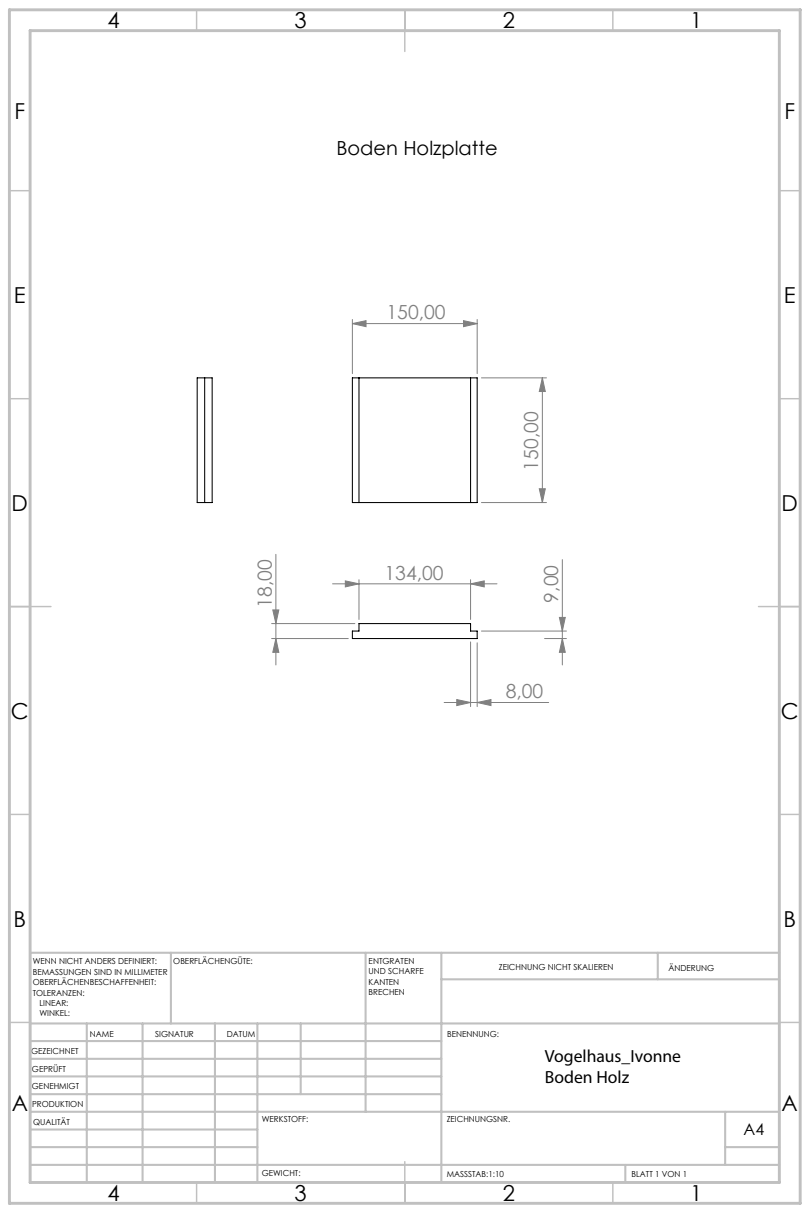
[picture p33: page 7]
ZEICHNUNG NICHT SKALIEREN; ÄNDERUNG; ENTGRATEN UND SCHARFE KANTEN BRECHEN; WENN NICHT ANDERS DEFINIERT:; OBERFLÄCHENGÜTE:

BEMASSUNGEN SIND IN MILLIMETER
OBERFLÄCHENBESCHAFFENHEIT:
TOLERANZEN:
LINEAR:
WINKEL:

NAME | SIGNATUR | DATUM | BENENNUNG: Vogelhaus_Ivonne Boden Holz
GEZEICHNET
GEPRÜFT
GENEHMIGT
PRODUKTION

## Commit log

2024-12-08 Create Anleitung Fertigung der Einzelteile.md
2024-12-08 Update Anleitung Fertigung der Einzelteile.md
2024-12-08 Rename Anleitung Fertigung der Einzelteile.md to Anleitung_Fertigung.md
